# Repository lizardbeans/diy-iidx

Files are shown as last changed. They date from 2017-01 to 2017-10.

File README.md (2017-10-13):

# Beatmania IIDX Controller (DIY)

<div style='float: center'>
  
</div>

<hr>

Check http://consandstuff.github.io/ for full instructions.

CODE INSTRUCTIONS:

Folder iidxsdvx/IIDX 9+1e+9leds/Arduino Leonardo/ contains 2 folders.

This folder contains the code for IIDX layout. (9 buttons, 1 encoder, 9 LEDs)

  * leovx: for low quality encoders (24ppr)
  
  * leovxhq: for high quality encoders (600ppr)
  
  If you have encoders with ppr different than 24ppr or 600ppr, you have to change some values inside the code.

<hr>

## Part List / Hardware

Things usde to make this controller.
You can find links here: http://consandstuff.github.io/rhythmcons/beatmania-iidx/iidx-small/pics/pic003.png

* Arduino Leonardo
* 1 High quality encoder (600ppr)
* 9 50x33 beatmania buttons
* 2 33x33 square buttons
* 9 Omron D2MV-01-1C3 (50gr.) microswitch
* Crimp connectors
* 14 moles 2.54 4pin wires with male and female connectors
* 1 perfboard

## Part List / Building Materials

Most of these parts should be CNC cut or laser cut (which is expensive). You can also use a cardboard box or wood MDF planks.
I used clear acrylic because it's cheaper, also using only one thickness will make it even less expensive.

**Main mounting plate**
* 3 or 5mm Black/Clear Acrylic with holes for button pad and disc encoder, also screw holes. I used 5mm clear acrylic, but I found out it's better to use 3mm black acrylic for the DJDAO FPS look.

**Button pads**
* 5mm Clear acrylic with holes for buttons and encoders. Black looks way better, I used clear.
  
**Turntable mounting plate**
* 5mm Clear acrylic with holes for encoder and screws.
  
**Turntable base**
* 2x5mm round discs with holes for encoder and mounting screws. Use this base to bring your turntable to your desirable height.
  
**Turntable disc**
* 5mm round disc with hole to fit the encoder. You can also cover this with a rubber skin for maximum gripness. The acrylic itself is really slippery.

**Mounting Box**
* I used 9-12mm MDF for the box walls, 5,5mm MDF for the base and 3mm MDF for the back door. Every cut and hole was made by me with a saw and some sandpaper. Using an electric saw and a sandpaper machine is a lot easier.

<hr>

**PIN DIAGRAM**

The pins are assigned to every button and encoder. You'll see that the PCB has many pins from A0 to A5, and from 0 to 13, so you'll have 19 pins in total. Remember that buttons use one pin, but encoders will use 2 pins. The PCB also has 3 grounds (GND) to choose from, and a 5v output for the 600ppr encoder.

**Beatmania IIDX Layout**

Tested working. See code included.

<table><thead>
<tr>
<th>Button</th>
<th style="text-align: center">Pin #</th>
<th style="text-align: center">Button #</th>
<th style="text-align: center">LED Pin #</th>
</tr>
</thead><tbody>
<tr>
<td>Start</td>
<td style="text-align: center">11</td>
<td style="text-align: center">Button 8</td>
<td style="text-align: center">2</td>
</tr>
<tr>
<td>VFX</td>
<td style="text-align: center">12</td>
<td style="text-align: center">Button 9</td>
<td style="text-align: center">3</td>
</tr>
<tr>
<td>Button 1</td>
<td style="text-align: center">13</td>
<td style="text-align: center">Button 1</td>
<td style="text-align: center">4</td>
</tr>
<tr>
<td>Button 2</td>
<td style="text-align: center">A0</td>
<td style="text-align: center">Button 2</td>
<td style="text-align: center">5</td>
</tr>
<tr>
<td>Button 3</td>
<td style="text-align: center">A1</td>
<td style="text-align: center">Button 3</td>
<td style="text-align: center">6</td>
</tr>
<tr>
<td>Button 4</td>
<td style="text-align: center">A2</td>
<td style="text-align: center">Button 4</td>
<td style="text-align: center">7</td>
</tr>
<tr>
<td>Button 5</td>
<td style="text-align: center">A3</td>
<td style="text-align: center">Button 5</td>
<td style="text-align: center">8</td>
</tr>
<tr>
<td>Button 6</td>
<td style="text-align: center">A4</td>
<td style="text-align: center">Button 6</td>
<td style="text-align: center">9</td>
</tr>
<tr>
<td>Button 7</td>
<td style="text-align: center">A5</td>
<td style="text-align: center">Button 7</td>
<td style="text-align: center">10</td>
</tr>
</tbody></table>

<table><thead>
<tr>
<th>ENCODERS</th>
<th style="text-align: center">DATA 1</th>
<th style="text-align: center">DATA 2</th>
</tr>
</thead><tbody>
<tr>
<td>Encoder Tuntable
<td style="text-align: center">0</td>
<td style="text-align: center">1</td>
</tr>
</tbody></table>

That leaves pins 2 to 10 for LEDS (9 LEDS, enough for each button)

## Assembly / Building the controller

1. Take the keypad of your choose. In this case I'll be using the IIDX&SDVX hybrid keypad
2. Prepare buttons with the ammount of pressure you like (button + spring + led + microswitch)
3. Insert every button where it belongs and screw the plastic nut from bellow
4. Insert both cheap encoders and screw the nut from above.
5. Mount the disc mounting plate on the Main mounting plate with the screws.
6. Mount the disc base on top of the Disc mounting plate with screws.
7. Mount th ehigh quality encoder in it's place with 3 screws.
8. Turn around the main mounting plate and mount the Leonardo and Protoboard/Breadboard
9. Wire every pin on the Leonardo PCB with a pin on the Breadboard using jumper wires.
10. Also wire one Ground to the PCB.
11. Mount the keypad plate on the Main plate with screws.
12. Wire every button and LED with the breadboard using jumper wires.
13. Connect the PCB to the computer using a USB cable, and using Arduino IDE load the code into the Arduino Leonardo.
14. Finally mount the plate onto the mounting box and mount the disc on the high quality encoder.

<hr>

## Gallery

[Here's the gallery, including other prototypes.](http://imgur.com/a/Vh7uL)

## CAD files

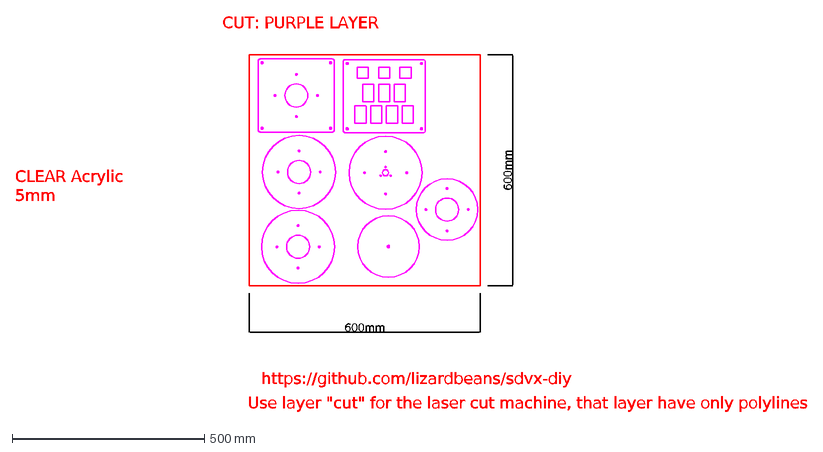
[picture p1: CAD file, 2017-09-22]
cad IIDX/IIDX - Top Plate 600x600x5mm (3 buttons).dxf
CLEAR Acrylic
5mm
CUT: PURPLE LAYER
600mm
https://github.com/lizardbeans/sdvx-diy
Use layer "cut" for the laser cut machine, that layer have only polylines

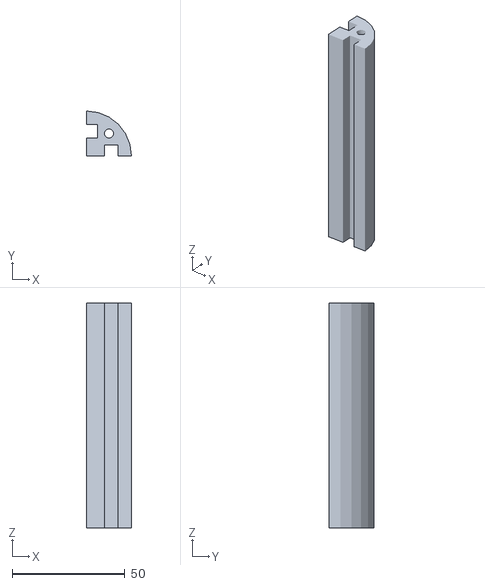
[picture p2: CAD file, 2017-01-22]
IIDX 9+1e+9leds/skp/edge.stl
20.0 x 20.0 x 100.0

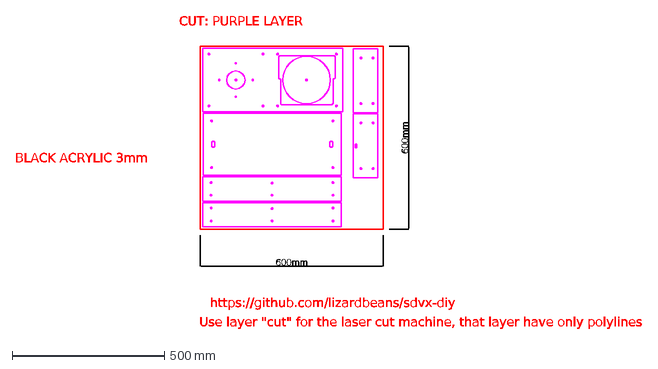
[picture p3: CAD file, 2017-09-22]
cad IIDX/IIDX - Side, bottom plate 600x600x3mm.dxf
BLACK ACRYLIC 3mm
CUT: PURPLE LAYER
600mm
https://github.com/lizardbeans/sdvx-diy
Use layer "cut" for the laser cut machine, that layer have only polylines

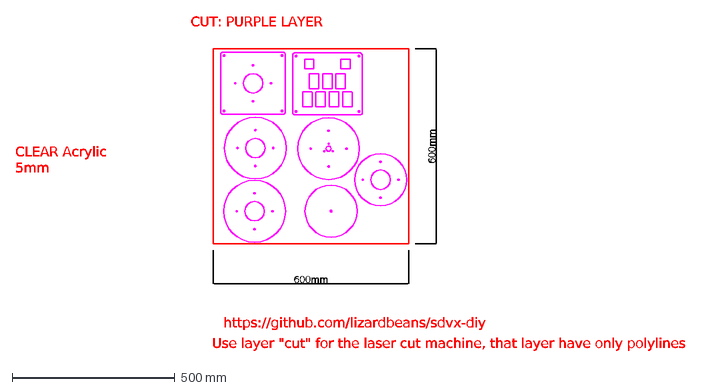
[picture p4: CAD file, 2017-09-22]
cad IIDX/IIDX - Top Plate 600x600x5mm.dxf
CLEAR Acrylic
5mm
CUT: PURPLE LAYER
600mm
https://github.com/lizardbeans/sdvx-diy
Use layer "cut" for the laser cut machine, that layer have only polylines

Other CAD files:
IIDX 9+1e+9leds/skp/edge.skp
cad IIDX/IIDX - Side, bottom plate 600x600x3mm.dwg
cad IIDX/IIDX - Top Plate 600x600x5mm (3 buttons).dwg
cad IIDX/IIDX - Top Plate 600x600x5mm.dwg

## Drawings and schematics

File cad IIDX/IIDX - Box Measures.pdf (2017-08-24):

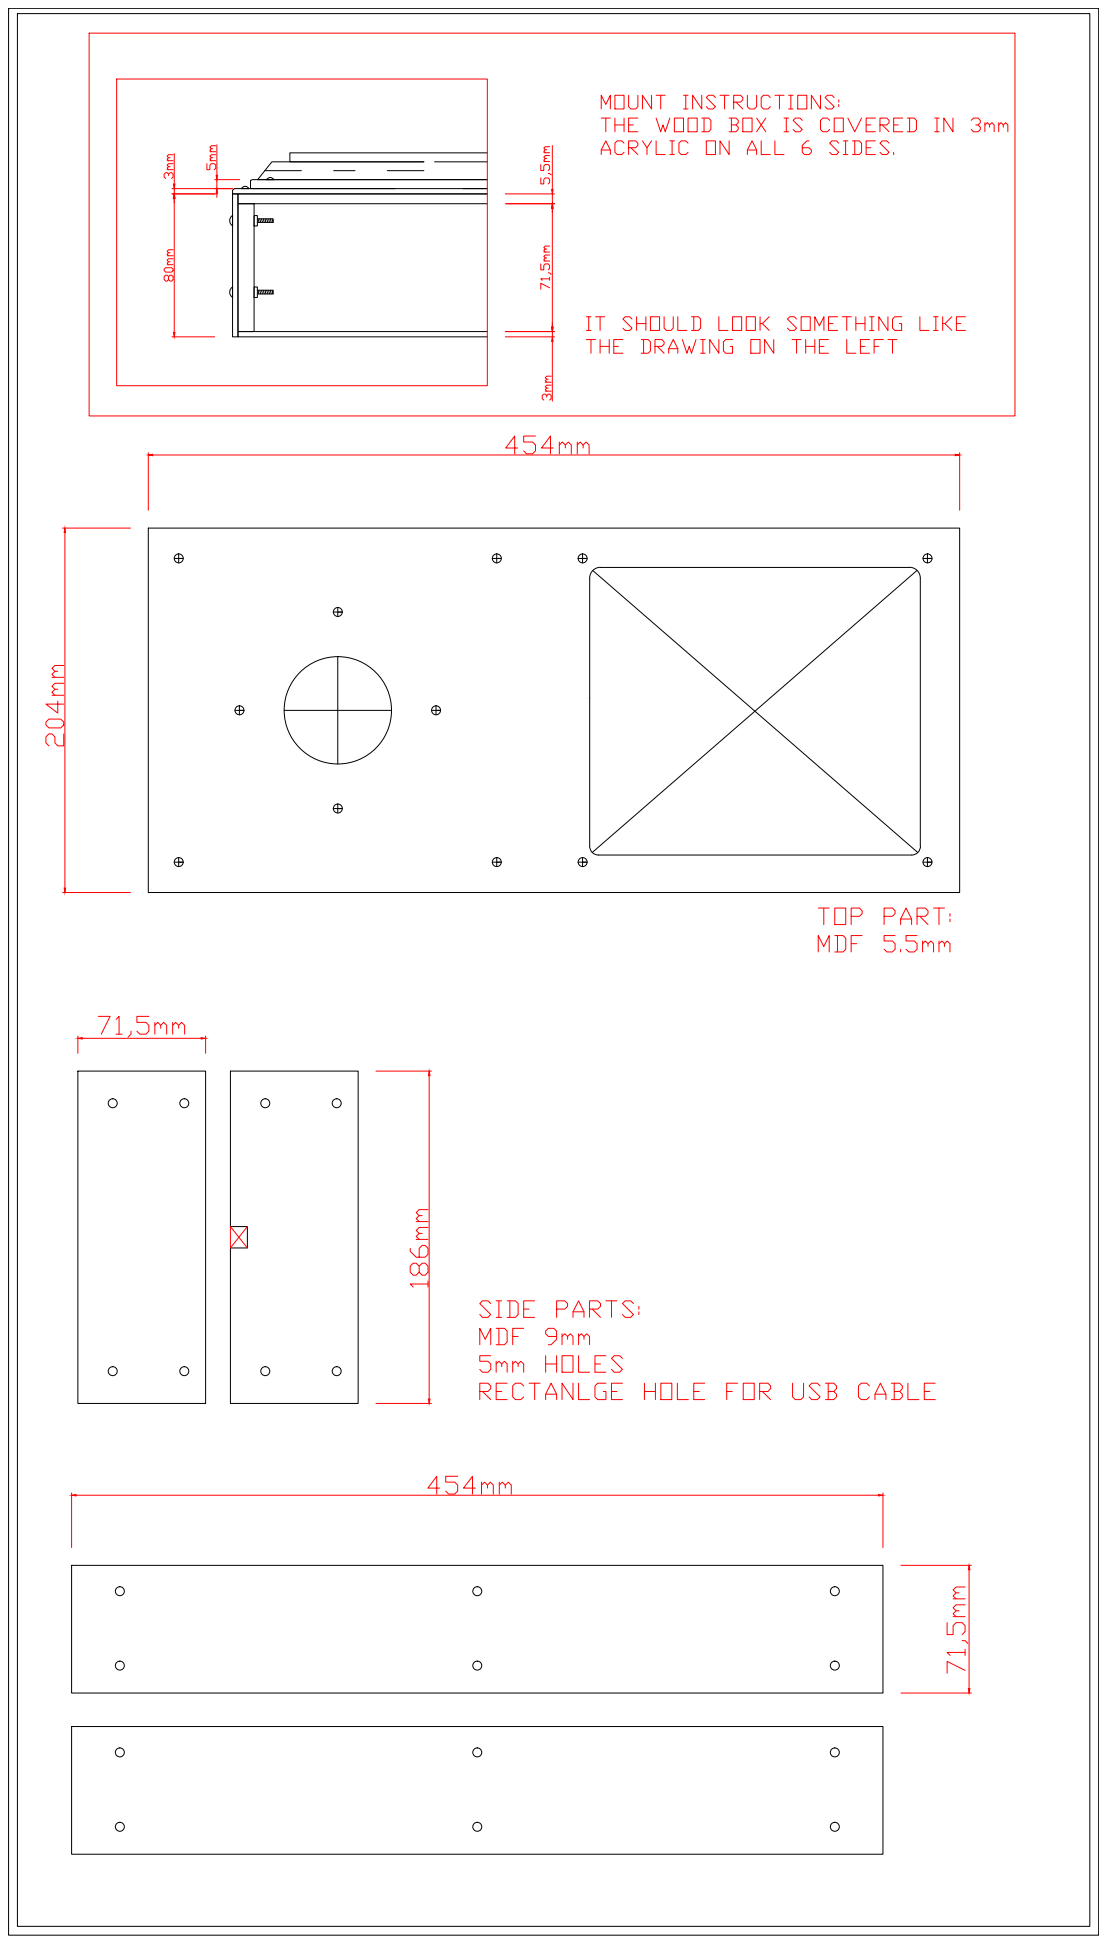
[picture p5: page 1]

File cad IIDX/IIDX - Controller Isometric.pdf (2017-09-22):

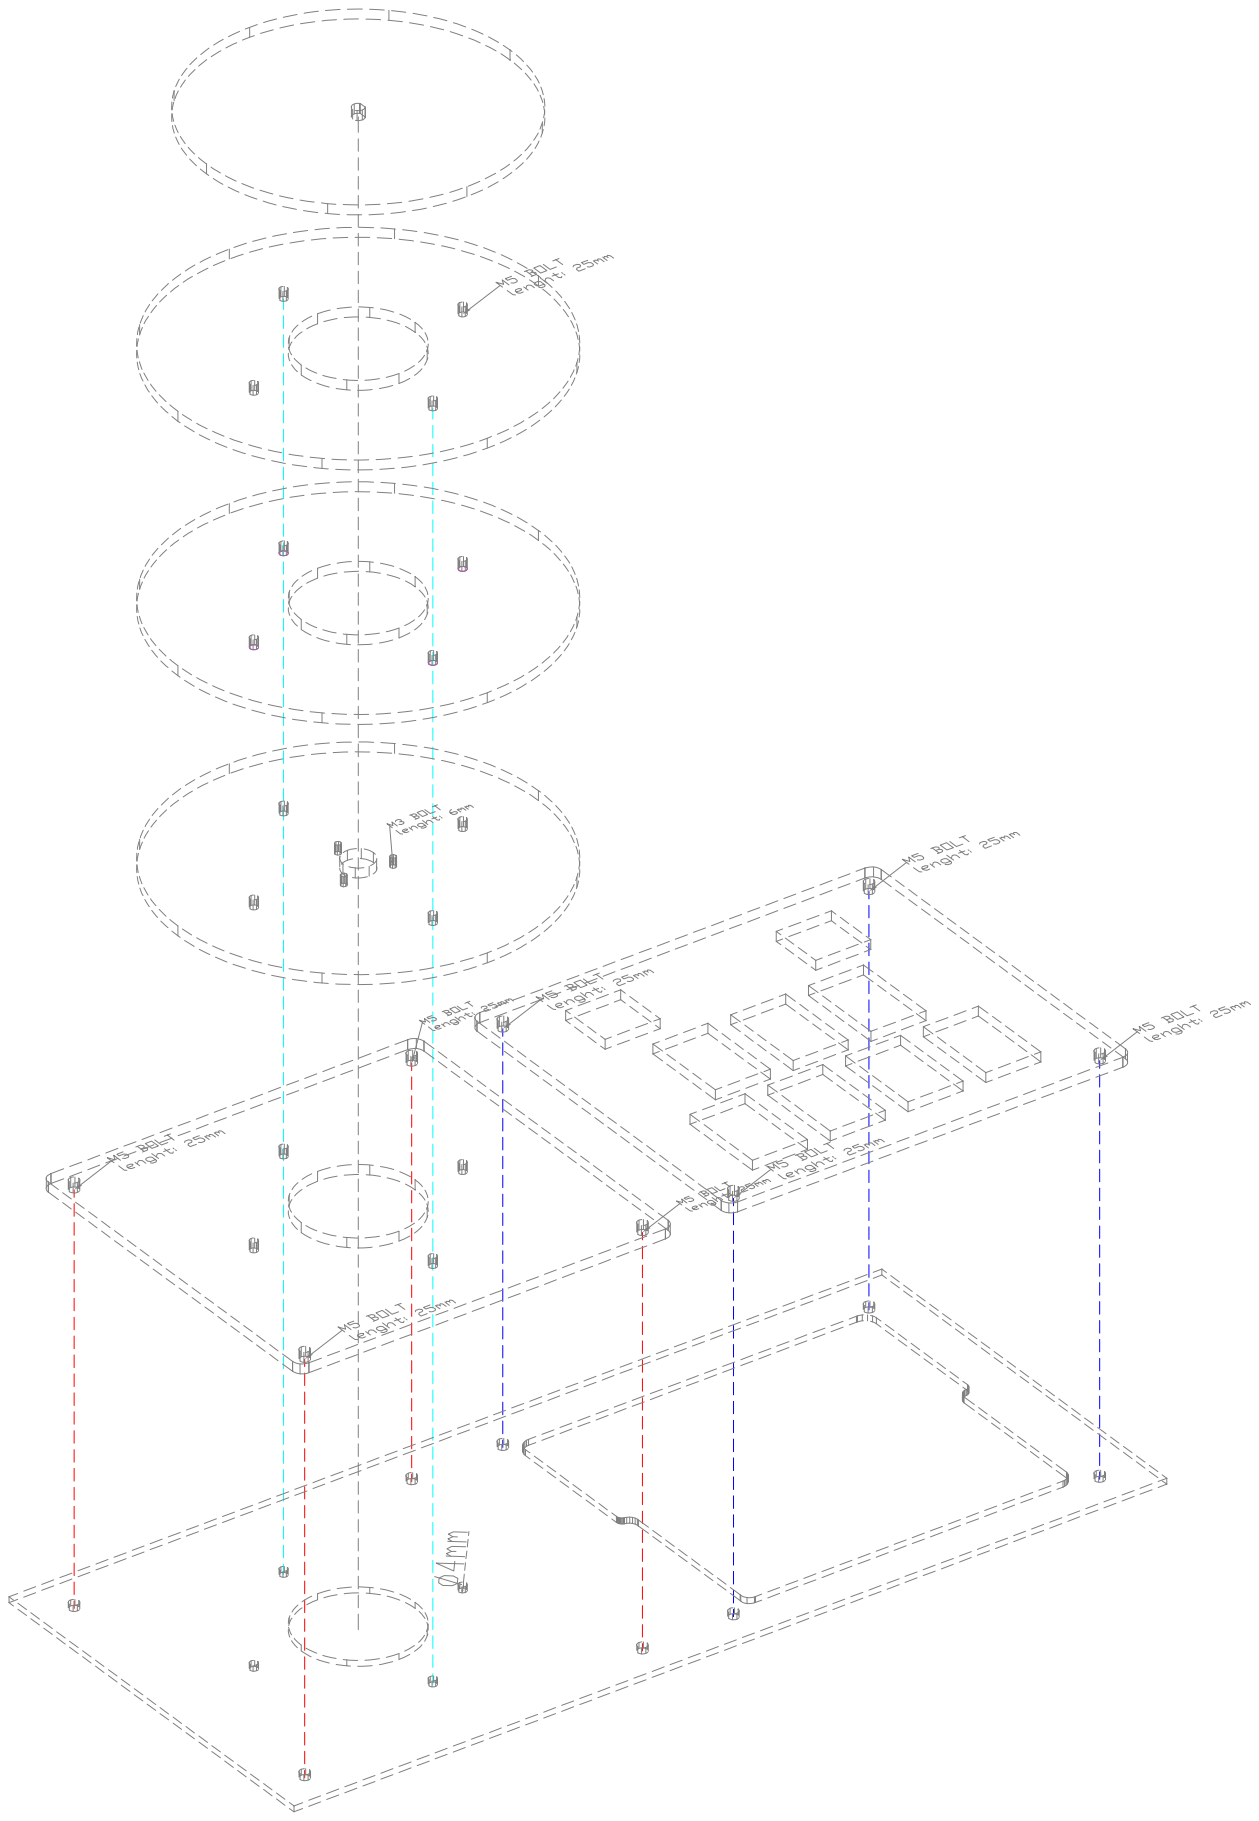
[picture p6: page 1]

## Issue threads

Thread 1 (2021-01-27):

Request For New Code

JerryDaga, 2021-01-27:
I suggest to this code for beatmania IIDX d.i.y project..
Add LED light when pressing without game used to feel arcade style and about on encoders when i tried on beatmania IIDX Infinitas while spin the dics the song selection movement is so fast and non stop spin (scroll sellect) in small or big amout spin the encoder.

encoder use 600rpm (compact version)

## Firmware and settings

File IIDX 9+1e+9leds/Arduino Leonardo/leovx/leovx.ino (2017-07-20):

#include "iivx_leo.h"
#include "Encoder.h"
iivxReport_t report; 

#define REPORT_DELAY 2000
// Number of microseconds between HID reports
// 2000 = 500hz

// Options, change only these values

uint8_t buttonCount = 9;
uint8_t sysPin = 11;
uint8_t lightMode = 0;
// 0 = reactive lighting, 1 = HID lighting
uint8_t buttonPins[] = {11,12,13,18,19,20,21,22,23};
uint8_t ledPins[] = {2,3,4,5,6,7,8,9,10};
/* current pin layout
 *  pins 18 - 23 = A0 - A5
 *  pins 2 to 10 = LED 1 to 7
 *    connect pin to + termnial of LED
 *    connect ground to resistor and then - terminal of LED
 *  pins 11 and 12 = START and EFFECT
 *  pins 13, A0 to A5 = Button input 1 to 7
 *    connect button pin to ground to trigger button press
 *  pins 11 = system pin
 *    connect system pin to ground with a small button
 *      press together with other buttons to change lighting scheme
 *    system button + button 1 = reactive lighting
 *    system button + button 3 = HID lighting
 */
 
#define ENCODER_SENSITIVITY (double) 0.375
// encoder sensitivity = number of positions per rotation times 4 (24*4) / number of positions for HID report (256)
Encoder encL(0,1);
/*
 * connect encoders
 * Turntable to pins 0 and 1
 */

void lights(uint16_t lightDesc){
  for(int i=0;i<buttonCount;i++){
     if((lightDesc>>i)&1){
         digitalWrite(ledPins[i],HIGH);
     } else {
         digitalWrite(ledPins[i],LOW);
     }
  }
}

void setup() {
  delay(1000);
  // Setup I/O for pins
  for(int i=0;i<buttonCount;i++){
    pinMode(buttonPins[i],INPUT_PULLUP);
    pinMode(ledPins[i],OUTPUT);
  }
  pinMode(sysPin,INPUT_PULLUP);
  //setup interrupts
}

void loop() {
  // Read buttons
  for(int i=0;i<buttonCount;i++){
    if(digitalRead(buttonPins[i])!=HIGH){
      report.buttons |= (uint16_t)1 << i;
    } else {
      report.buttons &= ~((uint16_t)1 << i);
    }
  }
  // Read Encoders
  report.xAxis = (uint8_t)((int32_t)(encL.read() / ENCODER_SENSITIVITY) % 256);
  // Light LEDs
  if(lightMode==0){
    lights(report.buttons);
  } else {
    lights(iivx_led);
  }
  // Detect lighting changes
  if(digitalRead(sysPin)!=HIGH){
    if(report.buttons == 1){
      lightMode = 0;
    } else if (report.buttons == 4){
      lightMode = 1;
    } else if (report.buttons == 16){
      report.buttons = (uint16_t)1 << (buttonCount);
    } else if (report.buttons == 64){
      report.buttons = (uint16_t)1 << (buttonCount+1);
    }
  }
  // Send report and delay
  iivx.setState(&report);
  delayMicroseconds(REPORT_DELAY);
}

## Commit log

2017-01-22 Added files
    Rough code.
    High quality encoders (600ppr) not testes on controller.
    Modified code copied from: https://github.com/4yn/iivx
    [edge.skp, edge.stl]
2017-01-23 Added CAD files
    [IIDXSDVX box cut sketch.dwg, IIDXSDVX cut sketch.dwg]
2017-07-16 Fixed buttons not working
    FIxed start button not working. Reactive lighting by default
    [leovxhq.ino]
2017-07-20 Fixed PIN10 LED not working.
    [leovxhq.ino]
2017-07-20 Fixed LED light on pin 10
    [leovx.ino]
2017-08-16 I uploaded the wrong file. Shame on me.
    I'll be editing and uploading the right file
    [IIDXSDVX cut sketch.dwg]
2017-08-16 Outdated file
    [IIDXSDVX box cut sketch.dwg]
2017-08-16 Added fixed files and PDF sketch of the box
    [IIDX - Side, bottom plate 600x600x3mm.dwg, IIDX - Side, bottom plate 600x600x3mm.dxf, IIDX - Top Plate 600x600x5mm.dwg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]
2017-08-24 Fixed bolt holes on top plate.
    The holes were missaligned.
    I also added a better sketch for the wood box and also added a version of the top plate with 3 buttons for START, EFX and VFX.
    [IIDX - Side, bottom plate 600x600x3mm.dwg, IIDX - Side, bottom plate 600x600x3mm.dxf, IIDX - Top Plate 600x600x5mm (3 buttons).dwg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]
2017-09-05 Changed the diameter of the turntable base.
    [IIDX - Top Plate 600x600x5mm (3 buttons).dwg, IIDX - Top Plate 600x600x5mm (3 buttons).dxf, IIDX - Top Plate 600x600x5mm.dwg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]
2017-09-22 Fixed some little thing to make it better. Detail below:
    - Added fillet to all the button holes so it doesn't crack if you slam your fingers too much
    - Added 2 extra holes to fix the turntable. These holes are compatible with the new Turntable desing
    - Added an extra turntable base circle inside the same 60x60cm sheet so you can choose between various styles when putting the controller together.
    - Added a 3D isometric of the controller mounting.
    [IIDX - Side, bottom plate 600x600x3mm.dwg, IIDX - Side, bottom plate 600x600x3mm.dxf, IIDX - Top Plate 600x600x5mm (3 buttons).dwg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]
